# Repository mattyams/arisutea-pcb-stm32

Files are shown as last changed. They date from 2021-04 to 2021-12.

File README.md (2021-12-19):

# THIS IS STILL A WIP! NO GUARANTEES ON ANYTHING!
- [X] v0.3 STM32 PCBs ordered 05/01/21
- [X] Assemble Arisutea PCB once received 05/21/21
- [X] Assemble Acrylic Case to Arisutea STM32 design
- [X] Edit QMK firmware for Arisutea STM32 design
# Arisutea - Arisu Keyboard PCB with More Modifications...now with MORE!
## Disclaimer: Use these files at your own risk.
Fairly confident that this will be the first actual version (v0.3 because...reasons...) of the STM32 version of the Arisutea board. See the notes below on the modification for this version. You will need KiCad 5.99 to view/edit these files.

アリステア PCB designed using KiCad. The layout was originally created by FateNozomi, inspired by Lyn's EM7 and TGR Alice with some modification. The layout was then modified by CorruptedJef and robotictomato to add USB-C, ESD and to shift/add some keys. This inspired me to modify the layout further by adding an STM32 and the ability to swap your switches out whenever you want and to make some keys a little more permenant. I have designed many boards in the past but never a keyboard so this is my first crack at it and I figured why not go all out? If you notice any issue please open an issue and we can discuss!

Since the layout has been modified yet again I decided to give the project a new name, Arisutea, which translates to Alistair. Obviously keeping the theme running here. 

Key modifications to the PCB:
- STM32F072 MCU
  - STM32F102 can be used but a crystal will need to be placed at Y1 (v0.4 - not tested)
- Added in Kailh Hotswap sockets.
- Addition of full backspace position, connected to switch 59 (row 0, column 13).
  - Removed switch 63 and repositioned switch 59 to add full backspace position.
- USB-C ESD rework.
- Added LED indicators for CAPS and NUM lock as well as layer.
- Updated JSON layout file for this particular keyboard.
- Original mounting holes have been returned to their rightful place. The idea of widening them was good at the time for FR4 plates, but not very practical. I am redesigning the case to allow for brass inserts and standoffs to be installed so the PCB will be nice and snug. More on that later. FR4 plates still will work but you will have to drill the holes out manually. If you take this route....go forth cautiously adventurer.

Check out the iBOM [here](https://htmlpreview.github.io/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)! This was generated with [InteractiveHtmlBom](https://github.com/openscopeproject/InteractiveHtmlBom)!

Renders generated by [Tracespace](https://github.com/tracespace/tracespace).
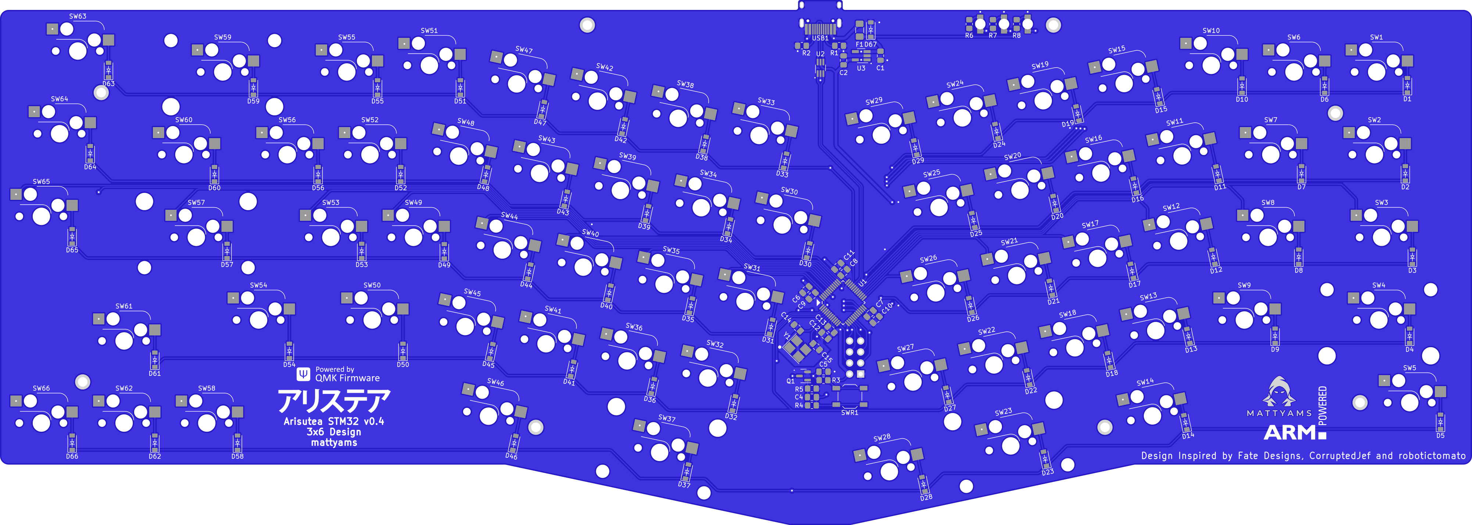
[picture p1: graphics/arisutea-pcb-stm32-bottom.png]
Arisutea

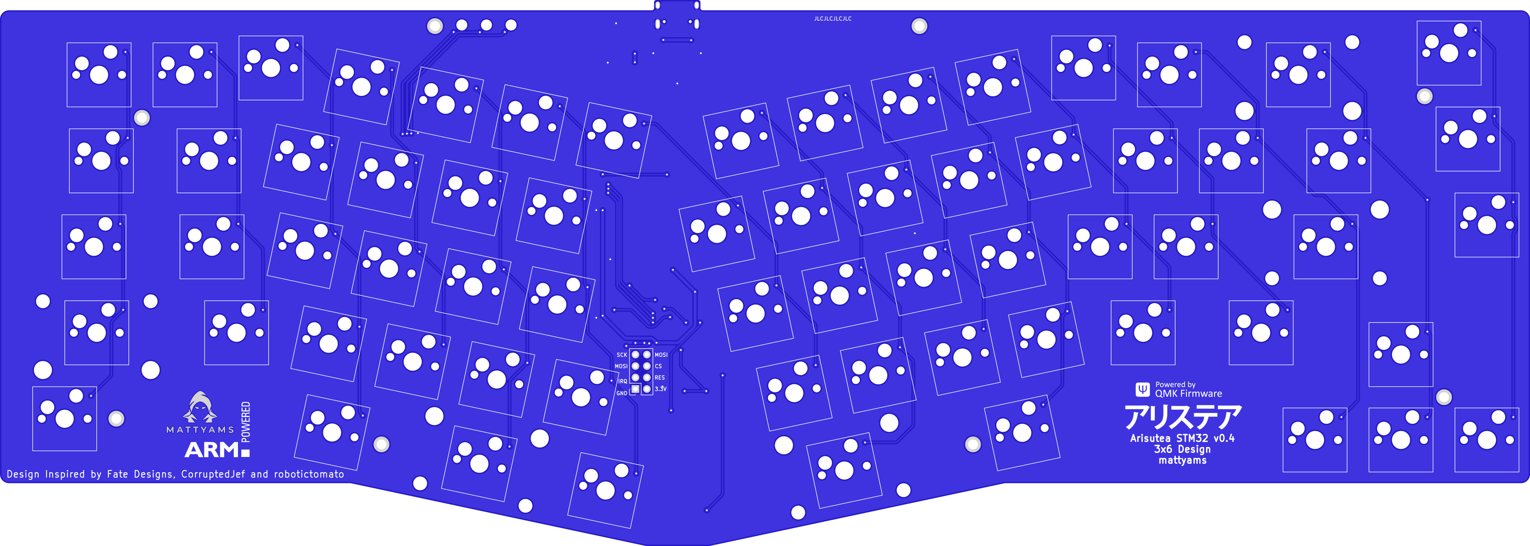
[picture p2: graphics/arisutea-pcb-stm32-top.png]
Arisutea-top

<!--
Just messing around with different switches.
![Arisutea-switches](https://i.imgur.com/Znw3HWQ.jpg)

The family, so far....
![Arisutea-builds](https://i.imgur.com/b8SRfIZ.jpg)

# Case Files for Ponoko

Case files are updated to reflect changes to the full backspace on switch 59 and can be found in the hardware folder under [arisutea-case](https://github.com/mattyams/arisutea-pcb/tree/master/hardware/arisutea-case).  The case I ordered with these changes just came in this week (3/6/2021) and it works very well with the changes I made to the full backspace and addition of the stablizer on the prototypes designed by CorruptedJef and robotictomato. There is now a "boxed" version of the case that I have made that is designed to work with some wrist rests that do not have the ortho shape. I have not tested this design yet but the prototype should be here this coming week (3/29/2021). There are now case files for version 0.6 that include the indicator LEDs, I have not ordered/tested these but will soon.

![Ponoko-case-1](https://imgur.com/FcGVhWI.jpg)
![Ponoko-case-2](https://imgur.com/hdUOVdj.jpg)
![Ponoko-case-3](https://imgur.com/IXYp1Ry.jpg)
![Ponoko-case-4](https://imgur.com/iDQcOTm.jpg)

# FR4 Plates and Case

Additionaly I have created files for FR4 plates to be made and used with this layout. These can be found in the hardware folder under [FR4_Plates](https://github.com/mattyams/arisutea-pcb/tree/master/hardware/FR4_Plates). The plates are designed to fit with the full backspace and non-stepped capslock. That being said, these will not work on the original Fate Designs PCB. Plates for the LED indicators have not been made just yet, but will be soon.

![FR4-Plates-1](https://imgur.com/oCfGKm7.jpg)
![FR4-Plates-2](https://imgur.com/L0FgL0s.jpg)
![FR4-Plates-3](https://imgur.com/QA77TCx.jpg)
![FR4-Plates-6](https://imgur.com/sJeoB8D.jpg)
## Exceprts from original designer, FateNozomi:

Key differences:
- Removed the extra [B] key on the right half and shifted the [NM,.?] row to the left by 0.25U.
- Shifted the 3 keys to the right and added arrow keys.
- Tweaked the bottom so that the 1.5U keys doesn't protrude out a little.

Shifting the [NM,.?] row to the left by 0.25U required quite some work on the arrangement of keys for the right half.
As a result, this does not give the same typing experience as Lyn's EM7 and TGR Alice.
Lyn's EM7 and TGR Alice uses the home row as the center point to vertically align both halves while I used the number row instead.
Due to the nature of staggered keyboards, aligning using the number row resulted in the home row not being aligned.

Disclaimer: Use these files at your own risk.

## Gerber Files
Download the gerber and BOM files under [releases](https://github.com/mattyams/arisutea-pcb/releases).

## PCB Assembly
For the components required, you may refer to the bill of materials included along with the release as reference or load up the design file in KiCad.
All the components can be soldered using a regular soldering iron, though soldering the USB-C receptacle might be the biggest hurdle. I have made an adjustment to the USB footprint to allow for a little more error when handsoldering. If needed, the BOM and POS file can be used on JLCPCB to assemble the PCB although I have not used their service I cannot confirm its accuracy or quality. -->

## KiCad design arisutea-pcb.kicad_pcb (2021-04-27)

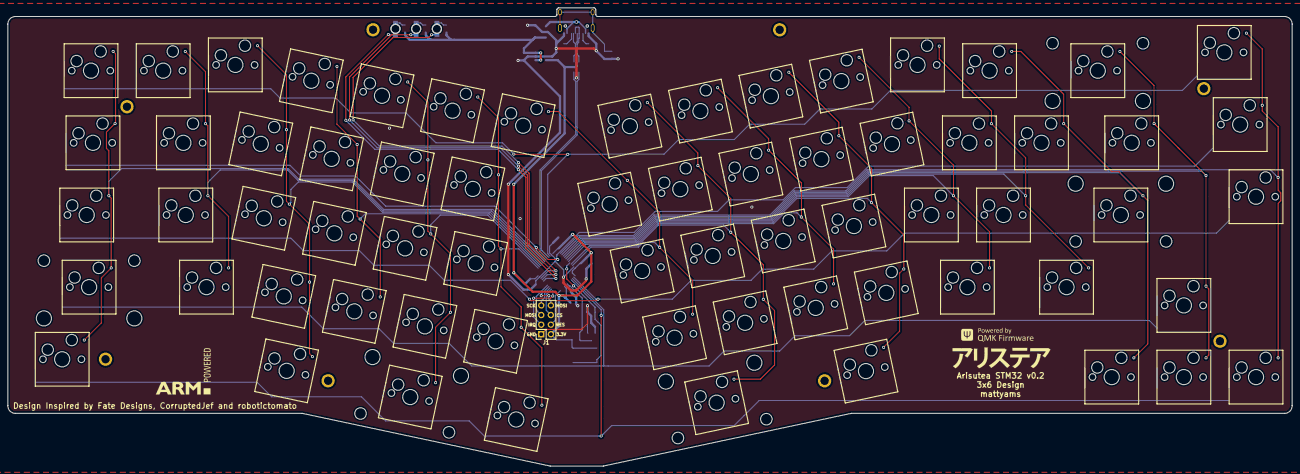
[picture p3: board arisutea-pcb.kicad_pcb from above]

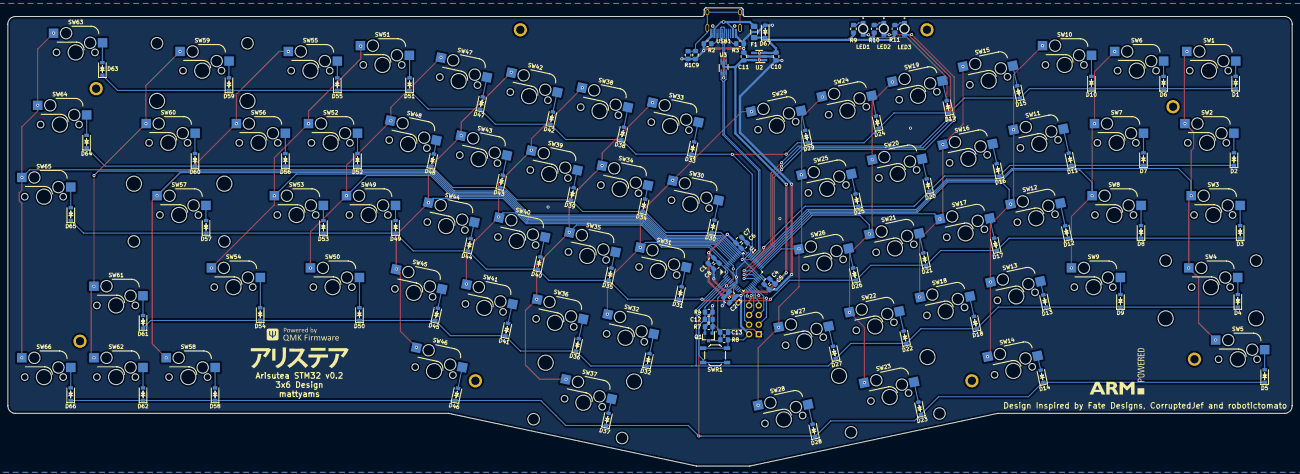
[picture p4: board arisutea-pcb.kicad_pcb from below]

Board: 2 copper layers, 339.1 x 121.0 mm, 180 parts (102 on the bottom side), 112 nets.

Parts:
C1, C4, C6, C8, C12, C13: 100n; C_0805_2012Metric_Pad1.18x1.45mm_HandSolder
C2: 10n; C_0805_2012Metric_Pad1.18x1.45mm_HandSolder
C3, C10, C11: 1u; C_0805_2012Metric_Pad1.18x1.45mm_HandSolder
C5, C7: 4.7u; C_0805_2012Metric_Pad1.18x1.45mm_HandSolder
C9: 4.7n; C_0805_2012Metric_Pad1.18x1.45mm_HandSolder
D1, D2, D3, D4, D5, D6, D7, D8, D9, D10, D11, D12, D13, D14, D15, D16, D17, D18, D19, D20, D21, D22, D23, D24, D25, D26, D27, D28, D29, D30, D31, D32, D33, D34, D35, D36, D37, D38, D39, D40, D41, D42, D43, D44, D45, D46, D47, D48, D49, D50, D51, D52, D53, D54, D55, D56, D57, D58, D59, D60, D61, D62, D63, D64, D65, D66: D; D_SOD-123
D67: SMF6.0CA; D_SOD-123
F1: 500mA; Fuse_1206_3216Metric_Pad1.42x1.75mm_HandSolder
H1, H2, H3, H4, H5, H6, H7, H8: ThroughHole; Generic-Mounthole
J1: Conn_Generic_Conn_01x08; PinHeader_2x04_P2.54mm_Vertical
LED1, LED2, LED3: LED; LED_IN-S124ARUW
LOGO1, LOGO2: arisutea_logo
LOGO3, LOGO4: arm_logo; Logo_ARM_powered
LOGO5, LOGO6: qmk_logo; Logo_QMK_Light
Q1: 2N7002; SOT-23
R1: 1M; R_0805_2012Metric_Pad1.20x1.40mm_HandSolder
R2, R3: 5k1; R_0805_2012Metric_Pad1.20x1.40mm_HandSolder
R4, R7, R8: 10K; R_0805_2012Metric_Pad1.20x1.40mm_HandSolder
R9, R10, R11: 470; R_0805_2012Metric_Pad1.20x1.40mm_HandSolder
SW1, SW6, SW7, SW8, SW9, SW10, SW11, SW12, SW13, SW14, SW15, SW16, SW17, SW18, SW19, SW20, SW21, SW22, SW24, SW25, SW26, SW27, SW28, SW29, SW30, SW31, SW32, SW33, SW34, SW35, SW36, SW38, SW39, SW40, SW41, SW42, SW43, SW44, SW45, SW46, SW47, SW48, SW49, SW50, SW51, SW52, SW53, SW55, SW56, SW58, SW61, SW62, SW63, SW64, SW65, SW66: SW_Push; SW_Hotswap_Kailh_1.00u
SW2, SW5, SW60: SW_Push; SW_Hotswap_Kailh_1.50u
SW3, SW54: SW_Push; SW_Hotswap_Kailh_1.75u
SW4: SW_Push; SW_Hotswap_Kailh_2.25u
SW23: SW_Push; SW_Hotswap_Kailh_2.00u_RevStab
SW37: SW_Push; SW_Hotswap_Kailh_2.75u_RevStab
SW57: SW_Push; SW_Hotswap_Kailh_2.25u_RevStab
SW59: SW_Push; SW_Hotswap_Kailh_2.00u
SWR1: SW_Push; SW_SPST_TL3342
U1: STM32F072-LQFP48; LQFP-48_7x7mm_P0.5mm
U2: TLV70233; SOT-23-5_HandSoldering
U3: NUF2221W1T2G; SOT-363_SC-70-6_Handsoldering
USB1: USB_C_HRO_TYPE-C-31-M-12-USB_Type-C; USB_C_Receptacle_HRO_TYPE-C-31-M-12-HandSoldering

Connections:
3.3V: C1.2, C2.2, C3.2, C4.2, C5.2, C6.2, C7.2, C8.2, C11.1, J1.8, R8.1, SWR1.2, U1.1, U1.9, U1.24, U1.36, U1.48, U2.5, U3.5
5V: C10.1, D67.1, F1.1, R9.1, R10.1, R11.1, U2.1, U2.3
D+: U1.33, U3.1
D-: U1.32, U3.3
GND: C1.1, C2.1, C3.1, C4.1, C5.1, C6.1, C7.1, C8.1, C9.2, C10.2, C11.2, C13.2, D67.2, J1.7, Q1.2, R1.2, R2.2, R3.1, R4.2, R7.2, U1.8, U1.23, U1.35, U1.47, U2.2, U3.2, USB1.A1, USB1.A12
NRST: C13.1, Q1.3, R8.2, U1.7
unnamed: C9.1, R1.1, USB1.S1
unnamed: C12.2, Q1.1, R7.1
unnamed: D1.2, SW1.1
unnamed: D2.2, SW2.1
unnamed: D3.2, SW3.1
unnamed: D4.2, SW4.1
unnamed: D5.2, SW5.1
unnamed: D6.2, SW6.1
unnamed: D7.2, SW7.1
unnamed: D8.2, SW8.1
unnamed: D9.2, SW9.1
unnamed: D10.2, SW10.1
unnamed: D11.2, SW11.1
unnamed: D12.2, SW12.1
unnamed: D13.2, SW13.1
unnamed: D14.2, SW14.1
unnamed: D15.2, SW15.1
unnamed: D16.2, SW16.1
unnamed: D17.2, SW17.1
unnamed: D18.2, SW18.1
unnamed: D19.2, SW19.1
unnamed: D20.2, SW20.1
unnamed: D21.2, SW21.1
unnamed: D22.2, SW22.1
unnamed: D23.2, SW23.1
unnamed: D24.2, SW24.1
unnamed: D25.2, SW25.1
unnamed: D26.2, SW26.1
unnamed: D27.2, SW27.1
unnamed: D28.2, SW28.1
unnamed: D29.2, SW29.1
unnamed: D30.2, SW30.1
unnamed: D31.2, SW31.1
unnamed: D32.2, SW32.1
unnamed: D33.2, SW33.1
unnamed: D34.2, SW34.1
unnamed: D35.2, SW35.1
unnamed: D36.2, SW36.1
unnamed: D37.2, SW37.1
unnamed: D38.2, SW38.1
unnamed: D39.2, SW39.1
unnamed: D40.2, SW40.1
unnamed: D41.2, SW41.1
unnamed: D42.2, SW42.1
unnamed: D43.2, SW43.1
unnamed: D44.2, SW44.1
unnamed: D45.2, SW45.1
unnamed: D46.2, SW46.1
unnamed: D47.2, SW47.1
unnamed: D48.2, SW48.1
unnamed: D49.2, SW49.1
unnamed: D50.2, SW50.1
unnamed: D51.2, SW51.1
unnamed: D52.2, SW52.1
unnamed: D53.2, SW53.1
unnamed: D54.2, SW54.1
unnamed: D55.2, SW55.1
unnamed: D56.2, SW56.1
unnamed: D57.2, SW57.1
unnamed: D58.2, SW58.1
unnamed: D59.2, SW59.1
unnamed: D60.2, SW60.1
unnamed: D61.2, SW61.1
unnamed: D62.2, SW62.1
unnamed: D63.2, SW63.1
unnamed: D64.2, SW64.1
unnamed: D65.2, SW65.1
unnamed: D66.2, SW66.1
unnamed: F1.2, USB1.A4, USB1.A9
unnamed: LED1.A, R9.2
unnamed: LED2.A, R10.2
unnamed: LED3.A, R11.2
unnamed: R2.1, USB1.B5
unnamed: R3.2, USB1.A5
unnamed: U3.4, USB1.A7, USB1.B7
unnamed: U3.6, USB1.A6, USB1.B6
SPI_CS: J1.4, U1.14
SPI_IRQ: J1.5, U1.13
SPI_MISO: J1.2, U1.16
SPI_MOSI: J1.3, U1.17
SPI_RES: J1.6, U1.12
SPI_SCK: J1.1, U1.15
boot0: C12.1, R4.1, SWR1.1, U1.44
col0: SW1.2, SW2.2, SW3.2, SW4.2, SW5.2, U1.30
col1: SW6.2, SW7.2, SW8.2, SW9.2, U1.29
col2: SW10.2, SW11.2, SW12.2, SW13.2, SW14.2, U1.28
col3: SW15.2, SW16.2, SW17.2, SW18.2, U1.27
col4: SW19.2, SW20.2, SW21.2, SW22.2, SW23.2, U1.26
col5: SW24.2, SW25.2, SW26.2, SW27.2, SW28.2, U1.25
col6: SW29.2, SW30.2, SW31.2, SW32.2, U1.46
col7: SW33.2, SW34.2, SW35.2, SW36.2, SW37.2, U1.45
col8: SW38.2, SW39.2, SW40.2, SW41.2, U1.43
col9: SW42.2, SW43.2, SW44.2, SW45.2, SW46.2, U1.42
col10: SW47.2, SW48.2, SW49.2, SW50.2, U1.41
col11: SW51.2, SW52.2, SW53.2, SW54.2, U1.40
col12: SW55.2, SW56.2, SW57.2, SW58.2, U1.39
col13: SW59.2, SW60.2, SW61.2, SW62.2, U1.38
col14: SW63.2, SW64.2, SW65.2, SW66.2, U1.37
led1: LED1.C, U1.22
led2: LED2.C, U1.21
led3: LED3.C, U1.20
row0: D1.1, D6.1, D10.1, D15.1, D19.1, D24.1, D29.1, D33.1, D38.1, D42.1, D47.1, D51.1, D55.1, D59.1, D63.1, U1.34
row1: D2.1, D7.1, D11.1, D16.1, D20.1, D25.1, D30.1, D34.1, D39.1, D43.1, D48.1, D52.1, D56.1, D60.1, D64.1, U1.31
row2: D3.1, D8.1, D12.1, D17.1, D21.1, D26.1, D31.1, D35.1, D40.1, D44.1, D49.1, D53.1, D57.1, D65.1, U1.2
row3: D4.1, D9.1, D13.1, D18.1, D22.1, D27.1, D32.1, D36.1, D41.1, D45.1, D50.1, D54.1, D61.1, U1.3
row4: D5.1, D14.1, D23.1, D28.1, D37.1, D46.1, D58.1, D62.1, D66.1, U1.4

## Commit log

2021-04-05 initial STM32 design
    [arisutea-pcb.kicad_pcb, arisutea-pcb.sch, matrix.sch]
2021-04-07 routing and placement work
    [arisutea-pcb.kicad_pcb, arisutea-pcb.sch, matrix.sch]
2021-04-27 big update
    Re-routed everything. Moved components around. Corrected gerbers and BOM/POS. Updated library. Added renders.
    [Arisutea_FR4_Plate_Bottom.kicad_pcb, Arisutea_FR4_Plate_Top.kicad_pcb, arisutea-pcb.kicad_pcb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]
2021-05-01 v0.3 for STM32 release
    First version of the STM32 to be sent to JLC for production.
    [arisutea-pcb.kicad_sch, arisutea-pcb.sch, matrix.kicad_sch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]
2021-05-22 trace add for ground
2021-07-09 rev0.4 update
    Small update to fix some non critical things.
    [arisutea-pcb.kicad_sch, matrix.kicad_sch]
2021-08-11 Add logo, edit ibom and readme
    [arisutea-pcb.kicad_sch, matrix.kicad_sch]
2021-08-11 Removed arisutea-case to replace with submodule
2021-08-11 Replaced case and fr4-plates directory with submodules
2021-08-11 removed plate gerber files
    These can be found in the plates subfolder gerber folder now.
2021-08-11 Update arisutea-fr4-plates
